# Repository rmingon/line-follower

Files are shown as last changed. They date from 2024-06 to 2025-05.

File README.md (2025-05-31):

## Line follower

first use video (https://youtube.com/shorts/s43NcmfP9Zg)

follow line video (https://youtube.com/shorts/unKHz3y9YLI)

# Line Follower Robot - ATmega2560 Based

This project is a Line Follower Robot using an ATmega2560 microcontroller. It features motor control, a reflective sensor array for line tracking, a fan controller, and voltage regulation.

### 3D views
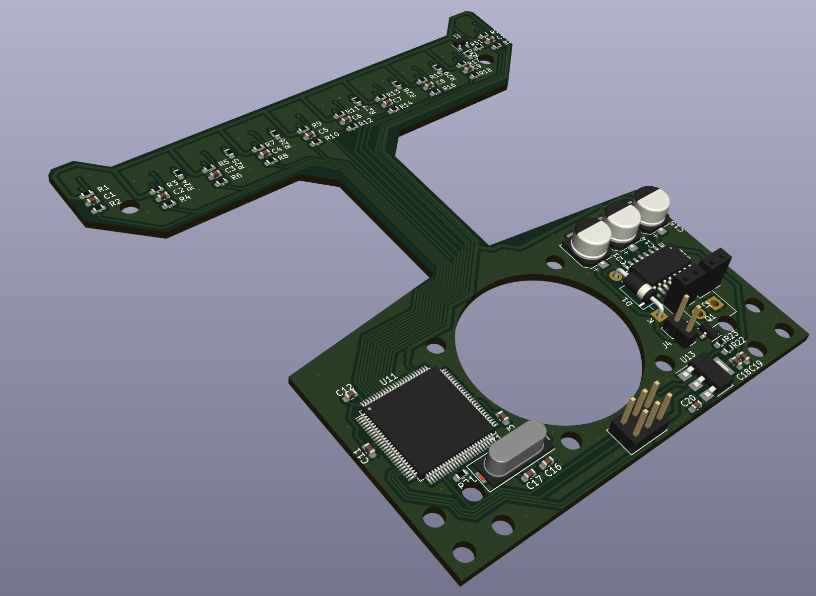
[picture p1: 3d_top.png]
3d top

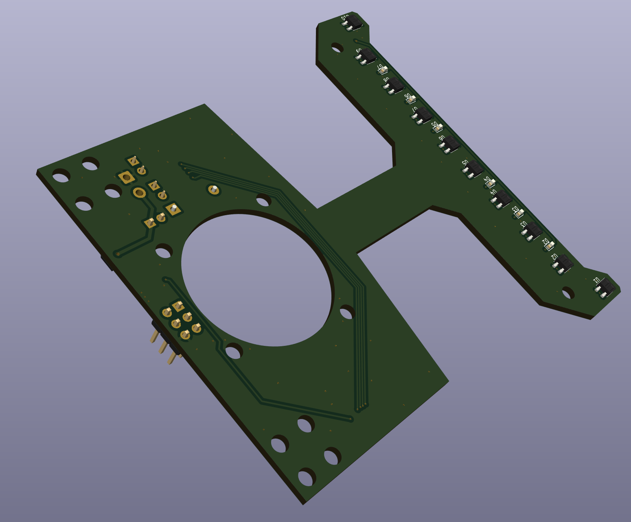
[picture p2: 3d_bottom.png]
3d bottom


## Features

- MCU: ATmega2560-16A
- 10x QRE1113GR reflective IR sensors
- 2x MX1508 motor drivers (H-bridge)
- MOSFET-based fan control (2N7002)
- Power via battery with 5V regulation (AMS1117)
- 6x status LEDs
- Standard AVR ISP programming header
- Custom-designed PCB

## Hardware Overview

- Sensors connect to MCU ADC pins
- Motor drivers controlled via PWM
- Fan controlled via GPIO and MOSFET
- 16 MHz crystal oscillator with 22pF caps
- Power from battery regulated to 5V

## Components

| Component | Part | Description |
|---|---|---|
| Microcontroller| ATmega2560-16A | Main processing unit |
| Motor Driver | MX1508 | H-bridge for motor control |
| Sensor | QRE1113GR | IR reflective sensor |
| Regulator | AMS1117-5.0 | 5V linear regulator |
| MOSFET | 2N7002 | Fan switching control |
| Oscillator | 16 MHz + 22pF | Clock for MCU |
| LED | Generic Red LED  | Status indicators |
| Fan | 5V Fan | Pin to floor |

## Key MCU Pin Mapping

| Feature | Pin (ATmega2560) |
|---|---|
| Motor A Control| PE4, PE5 |
| Motor B Control| PG5, PL7 |
| IR Sensors | PF0–PF9 |
| Fan Control | PD7 |
| LEDs | PA0–PA5 |

## PCB Layout

Two zones:
1. Sensor array in a linear top arrangement for line detection.
2. Bottom section contains MCU, drivers, power, and headers.

## Usage Steps

1. Connect a battery to `+BATT` input.
2. Upload firmware using AVR ISP (J5).
3. Place on track with visible black line.
4. Adjust PID tuning in firmware for better tracking.

## Development Tools

- KiCad for circuit & PCB design
- AVR-GCC or PlatformIO for firmware
- AVRDude for programming

## File Structure

```
/hardware
  schematic.jpeg
  pcb.png
/firmware
  main.c / main.cpp
  Makefile / platformio.ini
README.md
```

## Author

Created by Rmingon - Robotics Developer

### PCB
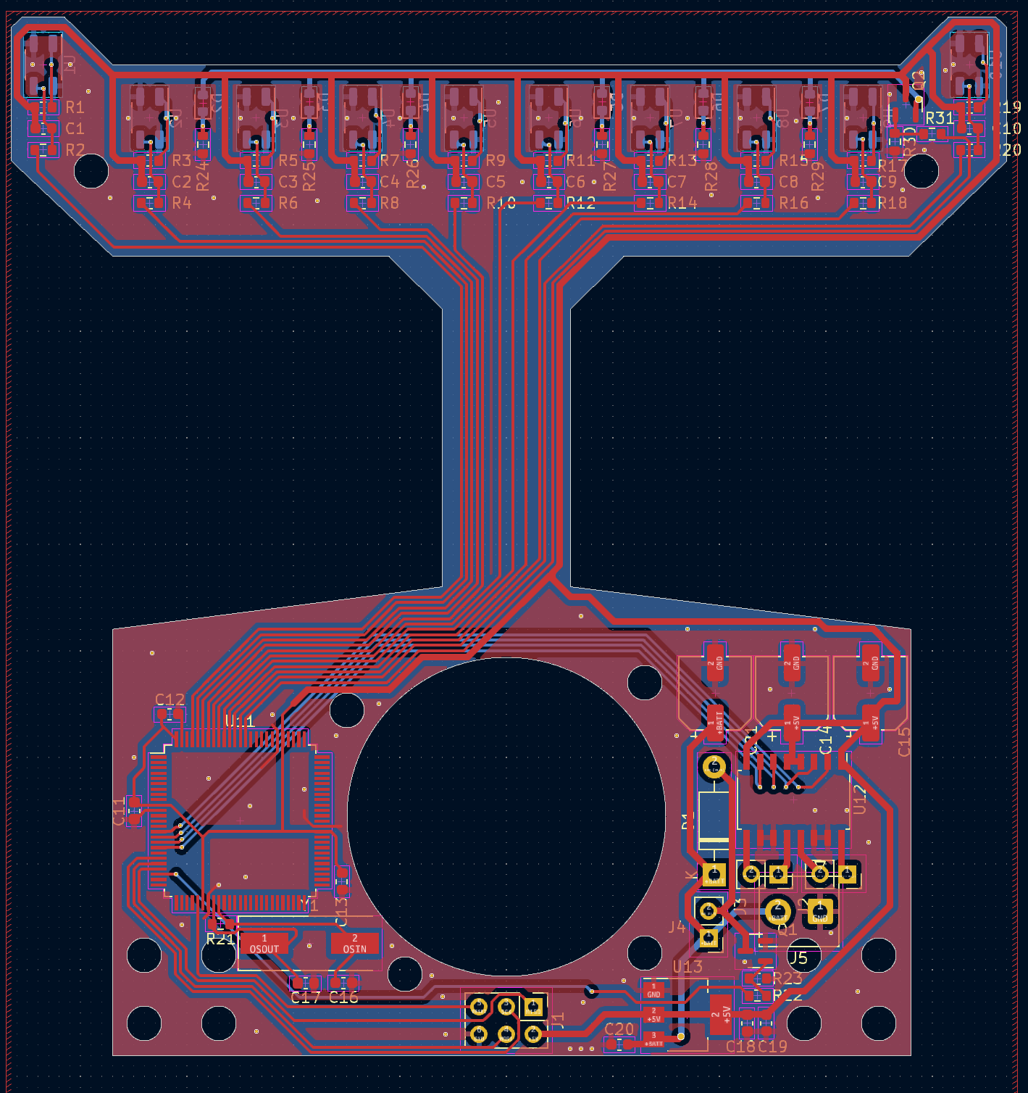
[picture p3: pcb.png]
pcb

### SCHEMATIC
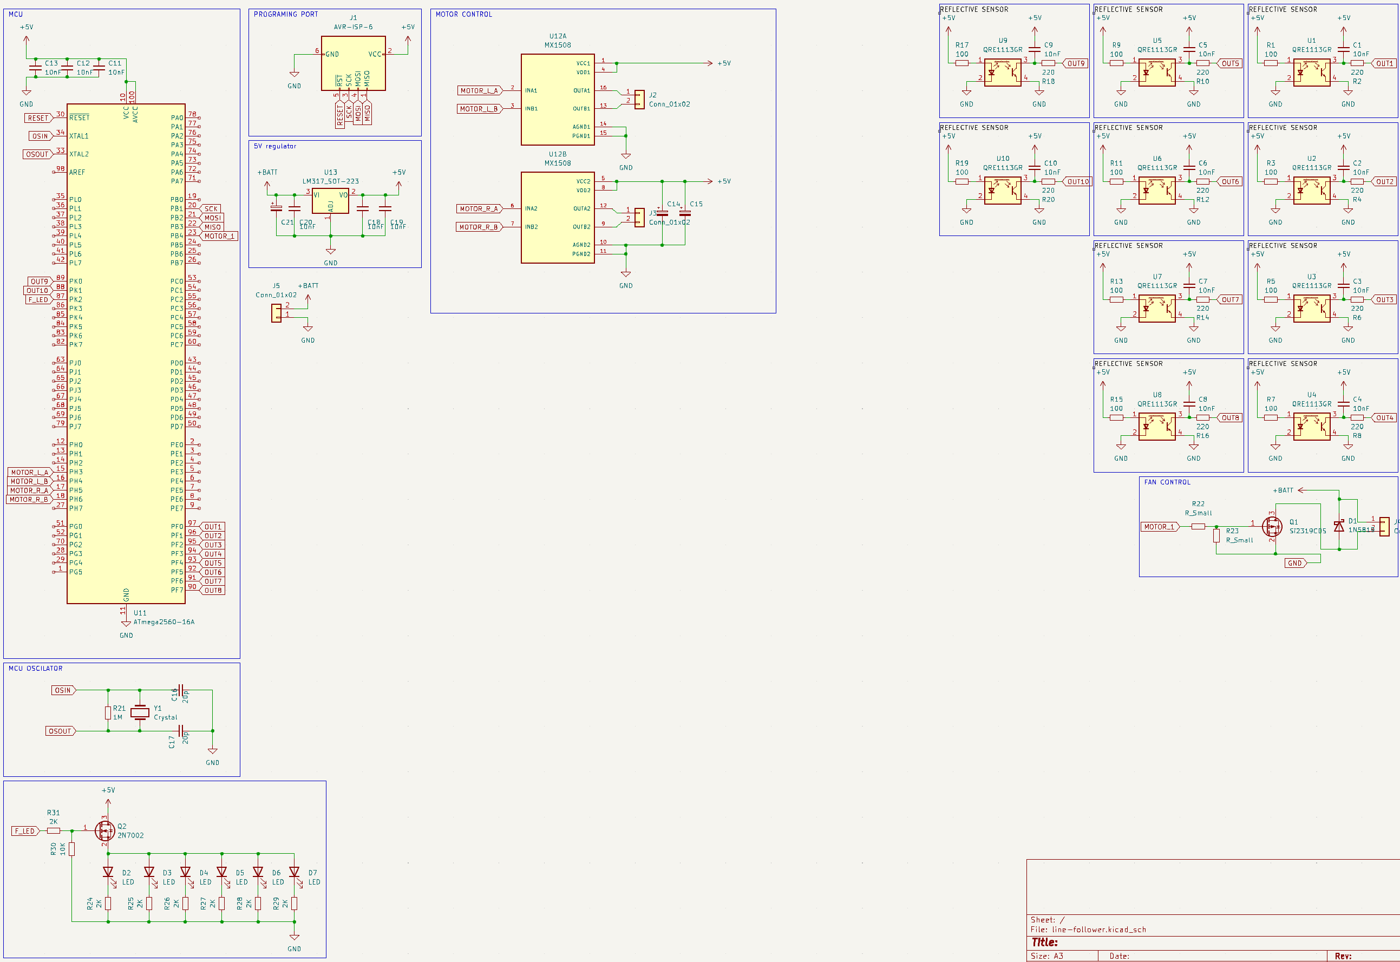
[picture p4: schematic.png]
schematic


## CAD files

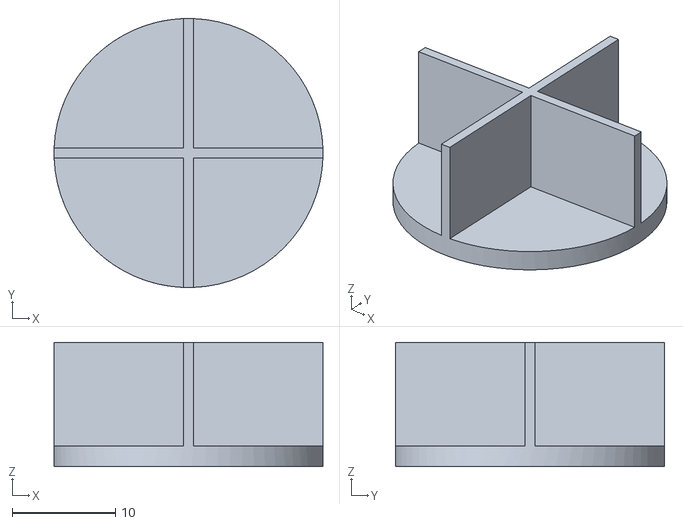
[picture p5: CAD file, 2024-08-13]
hardware/fan-propeller.stl
26.0 x 26.0 x 12.0

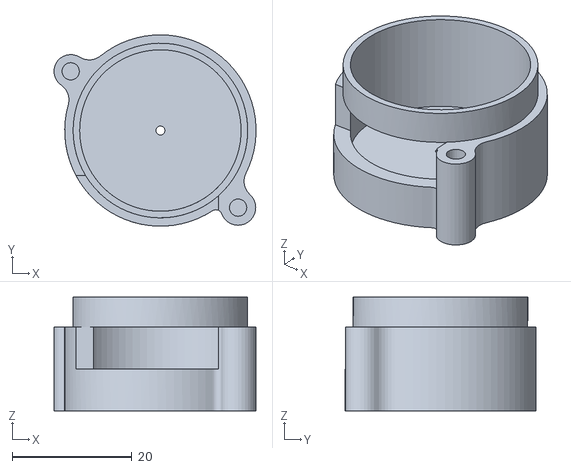
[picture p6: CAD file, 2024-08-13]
hardware/fan-case.stl
33.8 x 32.0 x 19.0

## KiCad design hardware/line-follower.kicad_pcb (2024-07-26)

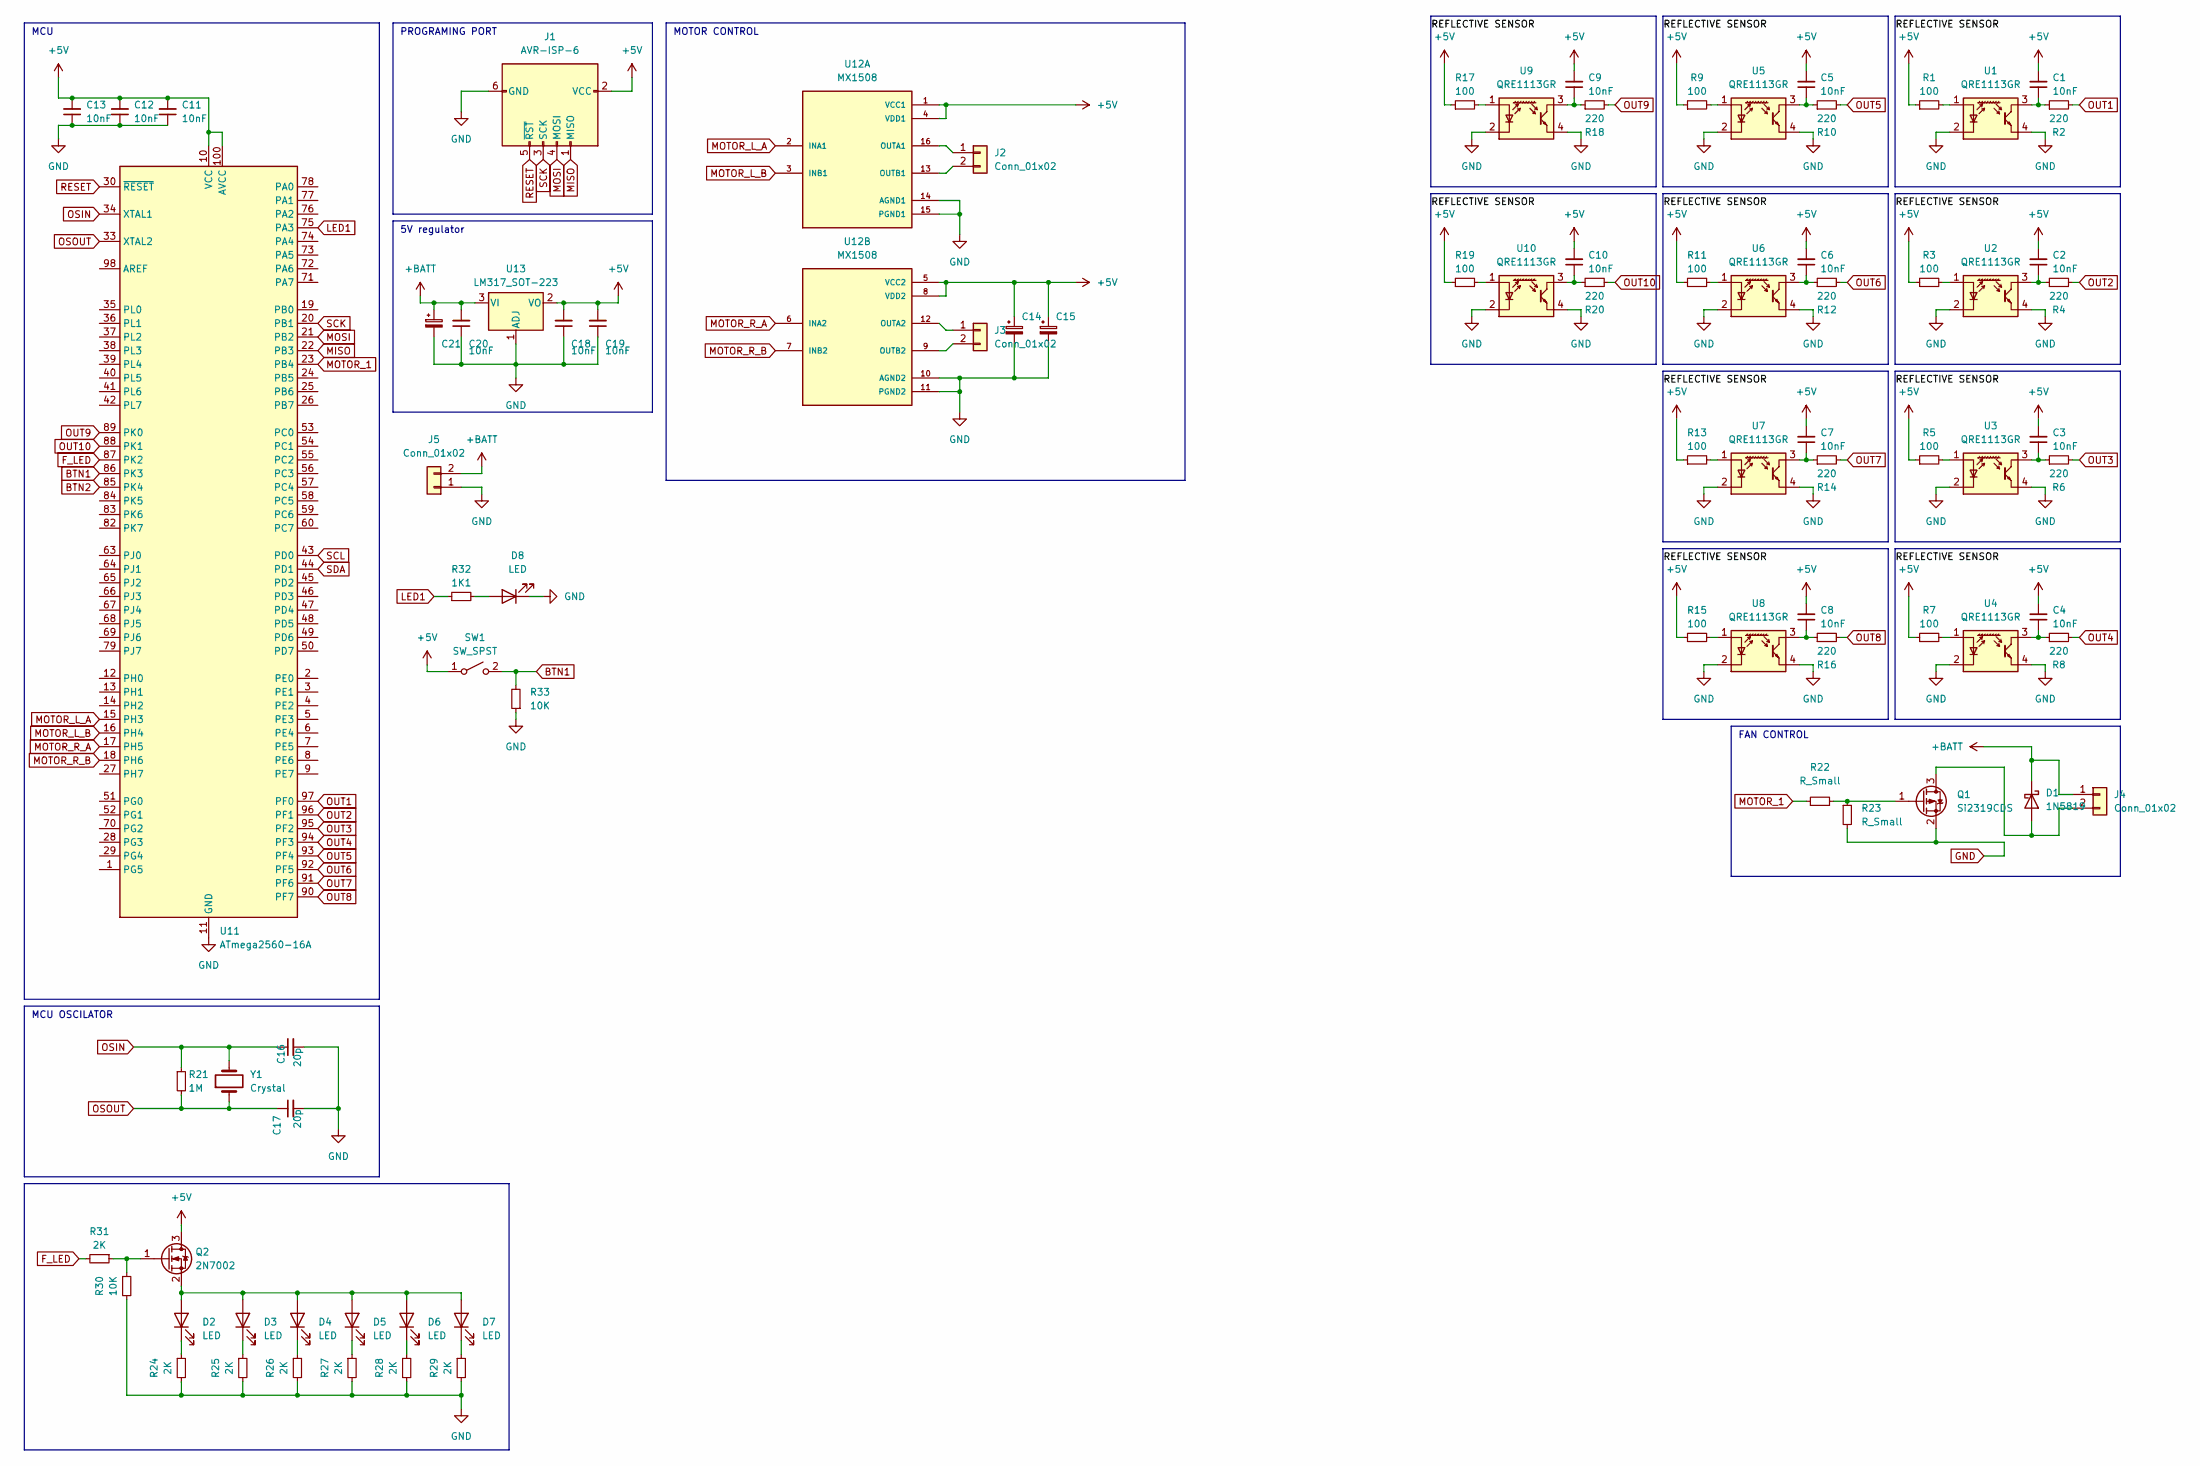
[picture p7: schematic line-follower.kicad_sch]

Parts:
C1, C2, C3, C4, C5, C6, C7, C8, C9, C10, C11, C12, C13, C18, C19, C20: 10nF; C_0603_1608Metric
C14, C15, C21: C_Polarized_Small; CP_Elec_6.3x4.9
C16, C17: 20p; C_0603_1608Metric
D1: 1N5819; D_DO-41_SOD81_P10.16mm_Horizontal
D2, D3, D4, D5, D6, D7, D8: LED; LED_0603_1608Metric
J1: AVR-ISP-6; PinHeader_2x03_P2.54mm_Vertical
J2, J3: Conn_01x02; PinSocket_1x02_P2.54mm_Vertical
J4: Conn_01x02; PinHeader_1x02_P2.54mm_Vertical
J5: Conn_01x02; TE_826576-2_1x02_P3.96mm_Vertical
Q1: Si2319CDS; SOT-23
Q2: 2N7002; SOT-23
R1, R3, R5, R7, R9, R11, R13, R15, R17, R19: 100; R_0603_1608Metric
R2, R4, R6, R8, R10, R12, R14, R16, R18, R20: 220; R_0603_1608Metric
R21: 1M; R_0603_1608Metric
R22, R23: R_Small; R_0603_1608Metric
R24, R25, R26, R27, R28, R29, R31: 2K; R_0603_1608Metric
R30, R33: 10K; R_0603_1608Metric
R32: 1K1; R_0603_1608Metric
SW1: SW_SPST; SW_SPST_FSMSM
U1, U2, U3, U4, U5, U6, U7, U8, U9, U10: QRE1113GR; OnSemi_CASE100CY
U11: ATmega2560-16A; TQFP-100_14x14mm_P0.5mm
U12: MX1508; SOIC-16W_5.3x10.2mm_P1.27mm
U13: LM317_SOT-223; SOT-223-3_TabPin2
Y1: Crystal; Crystal_SMD_HC49-SD

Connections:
+5V: C1.2, C2.2, C3.2, C4.2, C5.2, C6.2, C7.2, C8.2, C9.2, C10.2, C11.2, C12.2, C13.2, C14.1, C15.1, C18.2, C19.2, J1.2 (VCC), Q2.3 (D), R1.1, R3.1, R5.1, R7.1, R9.1, R11.1, R13.1, R15.1, R17.1, R19.1, SW1.1 (A), U11.10 (VCC), U11.31 (VCC), U11.61 (VCC), U11.80 (VCC), U11.100 (AVCC), U12.1 (VCC1), U12.4 (VDD1), U12.5 (VCC2), U12.8 (VDD2), U13.2 (VO)
+BATT: C20.2, C21.1, D1.1 (K), J4.1, J5.2, U13.3 (VI)
BTN1: R33.2, SW1.2 (B), U11.86 (PK3)
BTN2: U11.85 (PK4)
F_LED: R31.2, U11.87 (PK2)
GND: C11.1, C12.1, C13.1, C14.2, C15.2, C16.2, C17.2, C18.1, C19.1, C20.1, C21.2, D8.1 (K), J1.6 (GND), J5.1, Q1.2 (S), R23.2, R24.2, R25.2, R26.2, R27.2, R28.2, R29.2, R30.2, R33.1, U1.2 (K), U1.4, U2.2 (K), U2.4, U3.2 (K), U3.4, U4.2 (K), U4.4, U5.2 (K), U5.4, U6.2 (K), U6.4, U7.2 (K), U7.4, U8.2 (K), U8.4, U9.2 (K), U9.4, U10.2 (K), U10.4, U11.11 (GND), U11.32 (GND), U11.62 (GND), U11.81 (GND), U11.99 (GND), U12.10 (AGND2), U12.11 (PGND2), U12.14 (AGND1), U12.15 (PGND1), U13.1 (ADJ)
LED1: R32.1, U11.75 (PA3)
MISO: J1.1 (MISO), U11.22 (PB3)
MOSI: J1.4 (MOSI), U11.21 (PB2)
MOTOR_1: R22.1, U11.23 (PB4)
MOTOR_L_A: U11.15 (PH3), U12.2 (INA1)
MOTOR_L_B: U11.16 (PH4), U12.3 (INB1)
MOTOR_R_A: U11.17 (PH5), U12.6 (INA2)
MOTOR_R_B: U11.18 (PH6), U12.7 (INB2)
unnamed: C1.1, R2.1, U1.3
unnamed: C2.1, R4.1, U2.3
unnamed: C3.1, R6.1, U3.3
unnamed: C4.1, R8.1, U4.3
unnamed: C5.1, R10.1, U5.3
unnamed: C6.1, R12.1, U6.3
unnamed: C7.1, R14.1, U7.3
unnamed: C8.1, R16.1, U8.3
unnamed: C9.1, R18.1, U9.3
unnamed: C10.1, R20.1, U10.3
unnamed: D1.2 (A), J4.2, Q1.3 (D)
unnamed: D2.2 (A), D3.2 (A), D4.2 (A), D5.2 (A), D6.2 (A), D7.2 (A), Q2.2 (S)
unnamed: D2.1 (K), R24.1
unnamed: D3.1 (K), R25.1
unnamed: D4.1 (K), R26.1
unnamed: D5.1 (K), R27.1
unnamed: D6.1 (K), R28.1
unnamed: D7.1 (K), R29.1
unnamed: D8.2 (A), R32.2
unnamed: J2.1, U12.16 (OUTA1)
unnamed: J2.2, U12.13 (OUTB1)
unnamed: J3.1, U12.12 (OUTA2)
unnamed: J3.2, U12.9 (OUTB2)
unnamed: Q1.1 (G), R22.2, R23.1
unnamed: Q2.1 (G), R30.1, R31.1
unnamed: R1.2, U1.1 (A)
unnamed: R3.2, U2.1 (A)
unnamed: R5.2, U3.1 (A)
unnamed: R7.2, U4.1 (A)
unnamed: R9.2, U5.1 (A)
unnamed: R11.2, U6.1 (A)
unnamed: R13.2, U7.1 (A)
unnamed: R15.2, U8.1 (A)
unnamed: R17.2, U9.1 (A)
unnamed: R19.2, U10.1 (A)
OSIN: C16.1, R21.1, U11.34 (XTAL1), Y1.2
OSOUT: C17.1, R21.2, U11.33 (XTAL2), Y1.1
OUT1: R2.2, U11.97 (PF0)
OUT2: R4.2, U11.96 (PF1)
OUT3: R6.2, U11.95 (PF2)
OUT4: R8.2, U11.94 (PF3)
OUT5: R10.2, U11.93 (PF4)
OUT6: R12.2, U11.92 (PF5)
OUT7: R14.2, U11.91 (PF6)
OUT8: R16.2, U11.90 (PF7)
OUT9: R18.2, U11.89 (PK0)
OUT10: R20.2, U11.88 (PK1)
RESET: J1.5 (~RST), U11.30 (~RESET)
SCK: J1.3 (SCK), U11.20 (PB1)
SCL: U11.43 (PD0)
SDA: U11.44 (PD1)

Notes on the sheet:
MOTOR CONTROL
5V regulator
MCU OSCILATOR
PROGRAMING PORT
FAN CONTROL
MCU

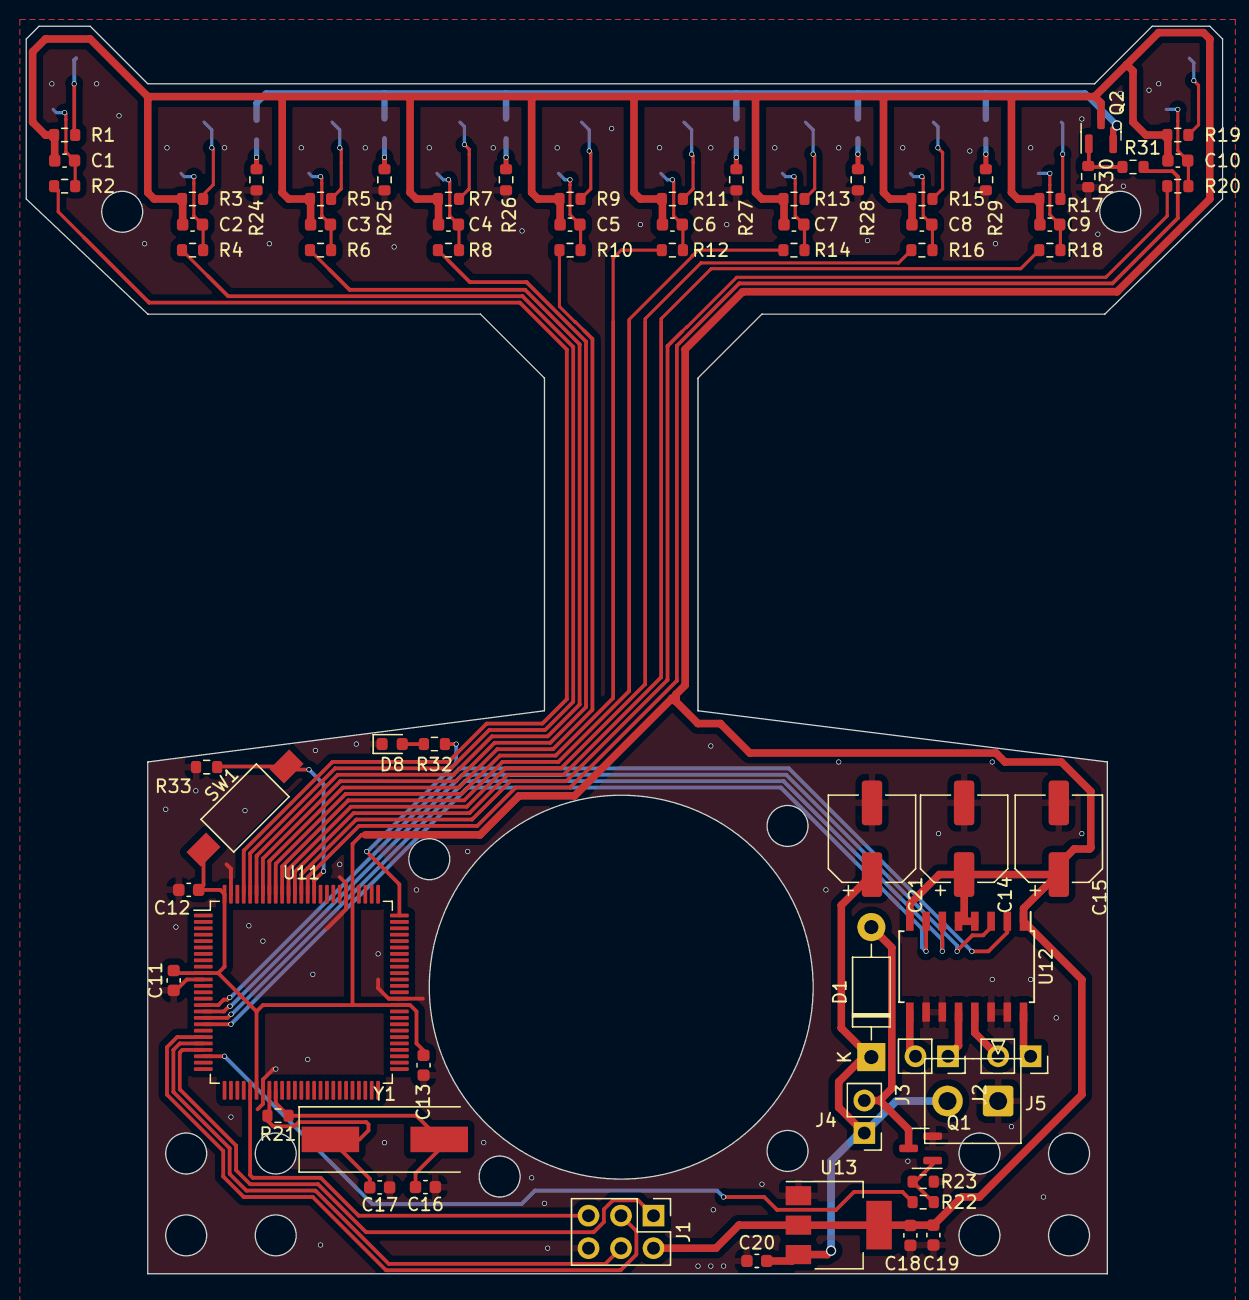
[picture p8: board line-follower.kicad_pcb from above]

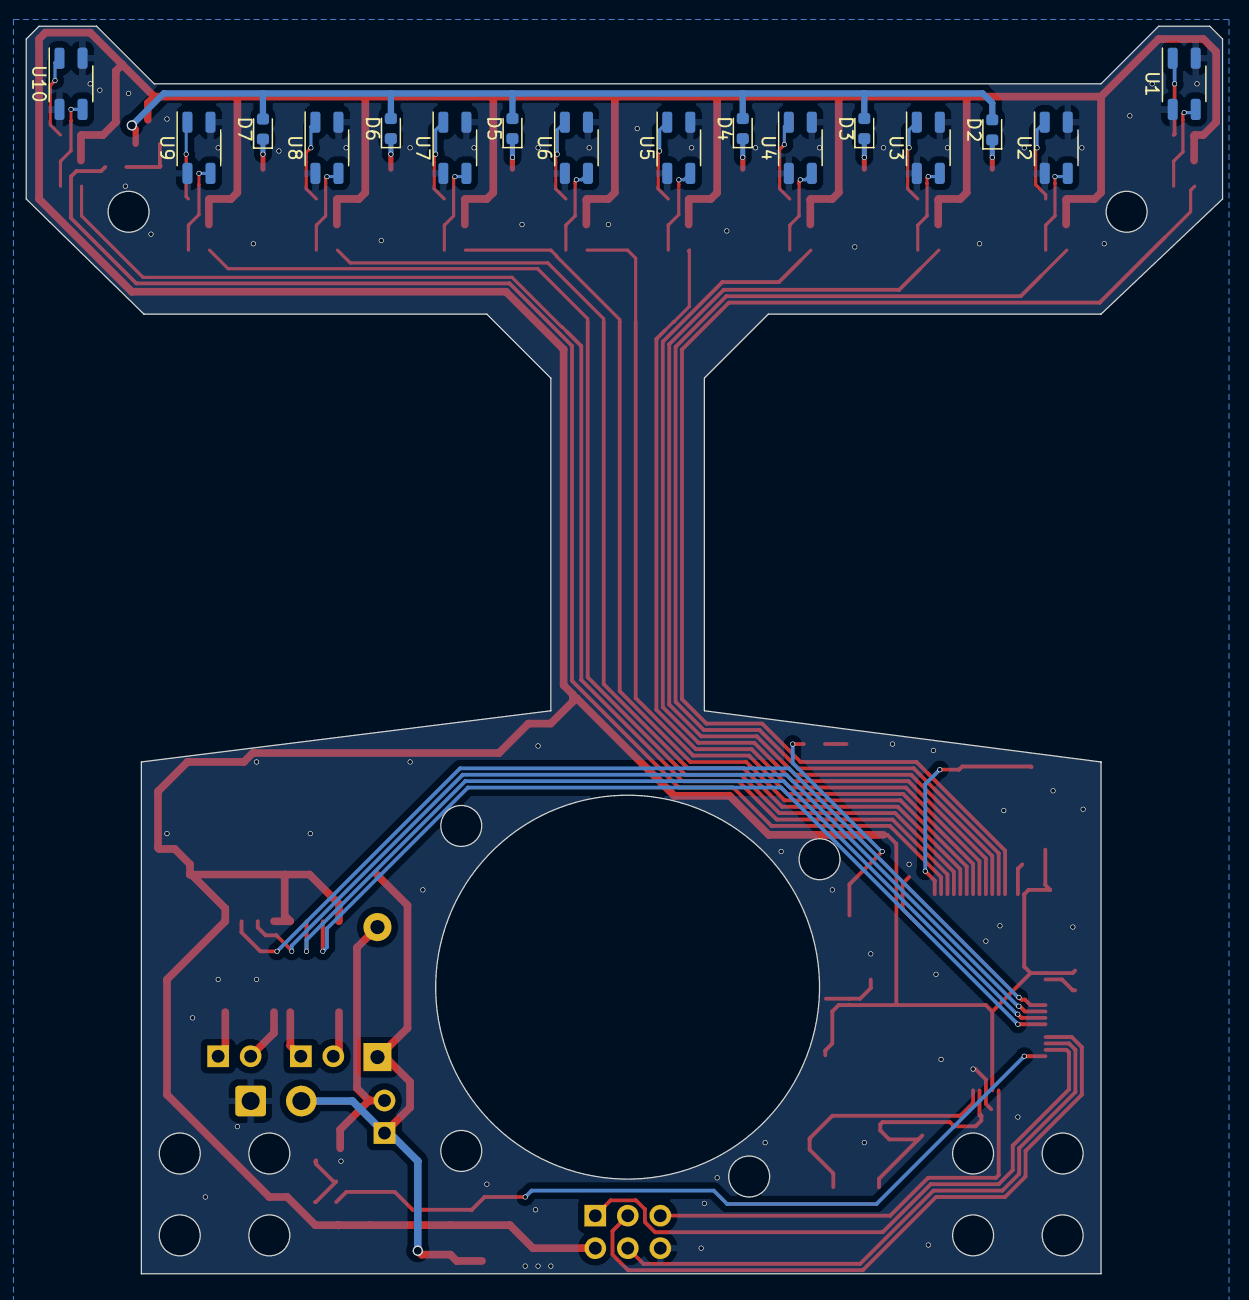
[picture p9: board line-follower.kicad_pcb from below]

Board: 2 copper layers, 93.5 x 97.5 mm, 84 parts (16 on the bottom side), 62 nets.

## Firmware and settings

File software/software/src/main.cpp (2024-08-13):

#include <Arduino.h>

#define SENSITIVITY 80

// IR PIN LEFT TO RIGHT
#define IR0 PIN_PF0
#define IR1 PIN_PF1
#define IR2 PIN_PF2
#define IR3 PIN_PF3
#define IR4 PIN_PF4
#define IR5 PIN_PF5
#define IR6 PIN_PF6
#define IR7 PIN_PF7
#define IR8 PIN_PK0
#define IR9 PIN_PK1

#define FAN PIN_PB4

// MX1508
#define MOTOR_L_A PIN_PH3
#define MOTOR_L_B PIN_PH4
#define MOTOR_R_A PIN_PH5
#define MOTOR_R_B PIN_PH6

// LEDS BOTTOM
#define LEDS PIN_PK2

#define BUTTON PIN_PK3

bool run = false;

void setup() {
  pinMode(PIN_PA3, OUTPUT);
  pinMode(BUTTON, INPUT);
  pinMode(FAN, OUTPUT);

  pinMode(LEDS, OUTPUT);
  
  pinMode(MOTOR_L_A, OUTPUT);
  pinMode(MOTOR_L_B, OUTPUT);
  pinMode(MOTOR_R_A, OUTPUT);
  pinMode(MOTOR_R_B, OUTPUT);
  analogWrite(MOTOR_L_A, 0);
  analogWrite(MOTOR_L_B, 0);
  analogWrite(MOTOR_R_A, 0);
  analogWrite(MOTOR_R_B, 0);
  
  pinMode(IR3, INPUT);
  pinMode(IR4, INPUT);
  pinMode(IR5, INPUT);
  pinMode(IR6, INPUT);
}

void loop() {
  if (digitalRead(BUTTON)) {
    delay(300);
    run = !run;
  }
  if (run) {
    // analogWrite(FAN, 10);
    
    digitalWrite(LEDS, HIGH);
    int ir4 = analogRead(IR4);
    if (ir4 > SENSITIVITY) {
      analogWrite(MOTOR_L_B, 60);
    } else {
      analogWrite(MOTOR_L_B, 0);
    }
    int ir5 = analogRead(IR5);
    if (ir5 > SENSITIVITY) {
      analogWrite(MOTOR_R_A, 60);
    } else {
      analogWrite(MOTOR_R_A, 0);
    }

  } else {
    
    digitalWrite(LEDS, LOW);
    analogWrite(FAN, 0);
    
    analogWrite(MOTOR_L_B, 0);
      
    analogWrite(MOTOR_R_A, 0);
  }

}

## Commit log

2024-06-29 add captors array
    [line-follower.kicad_pcb, line-follower.kicad_sch]
2024-06-29 array wiring
    [line-follower.kicad_pcb, line-follower.kicad_sch]
2024-06-30 add mcu
    [line-follower.kicad_sch]
2024-06-30 add hole for fan
    [line-follower.kicad_pcb, line-follower.kicad_sch]
2024-06-30 add regulator
    [line-follower.kicad_pcb, line-follower.kicad_sch]
2024-06-30 add battery connector
    [line-follower.kicad_pcb, line-follower.kicad_sch]
2024-06-30 add led + switch
    [line-follower.kicad_pcb, line-follower.kicad_sch]
2024-07-01 update cam path
    [line-follower.kicad_pcb]
2024-07-24 add motor test
2024-07-26 update version
    [line-follower.kicad_pcb, line-follower.kicad_sch]
2024-07-30 test fan
2024-08-12 change pwm
2024-08-13 add 3d fan
    [fan-case.stl, fan-propeller.stl]
